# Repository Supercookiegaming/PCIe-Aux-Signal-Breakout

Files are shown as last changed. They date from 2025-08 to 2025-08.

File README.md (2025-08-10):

# PCIe Auxiliary Signal Breakout Card


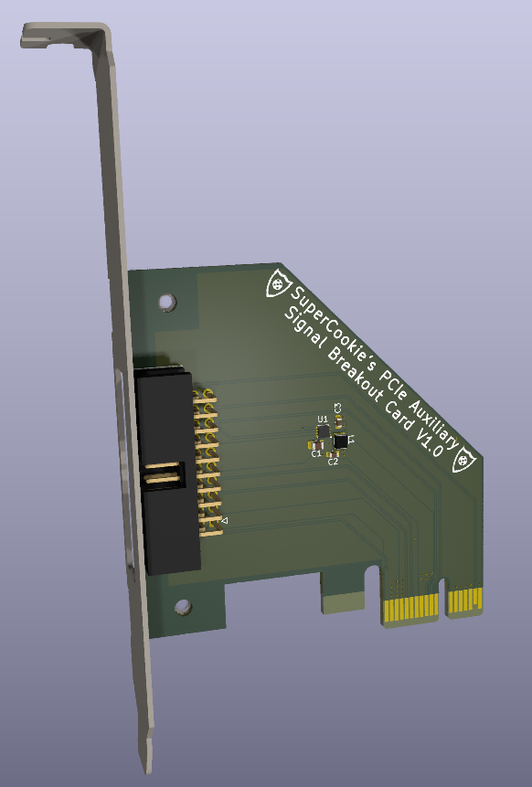
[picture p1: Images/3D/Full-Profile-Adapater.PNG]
3D Card Render


## Overview
The PCIe Auxiliary Signal Breakout Card is designed to make the auxiliary signals in a PCIe connection available to the user. This includes SMBus and JTAG. The card also provides 12V, 5V and 3.3V power and the PCIe reset signal which also functions as a 3.3V and 12V power good signal.

## Specifications

* 10W Total Power Output
    * Up to 3.0A on 3.3V
    * Up to 1.0A on 5V (optional)
    * Up to 0.5A on 12V
    * Up to 0.375A on 3.3V Aux
* Open-Drain SMBus
    * 3.3V Signal Levels
* IEEE Standard 1149.1 JTAG
    * 3.3V Signal Levels
* Always on 3.3V Aux rail
* Standard and Low Profile Brackets included

## Pinout

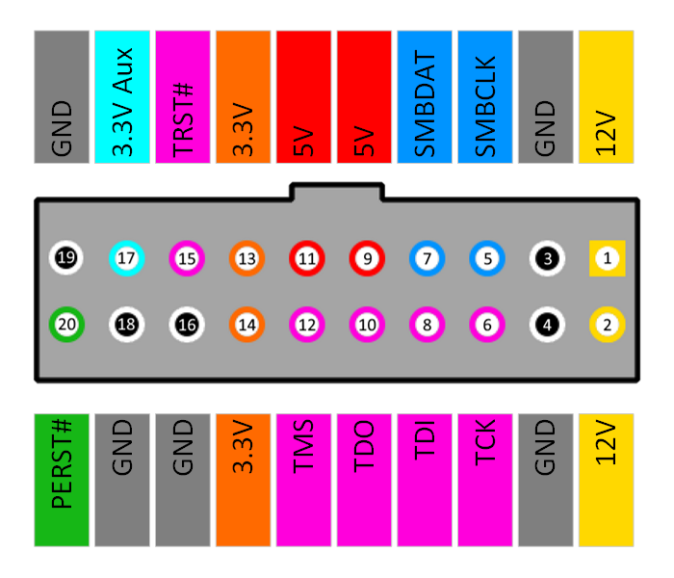
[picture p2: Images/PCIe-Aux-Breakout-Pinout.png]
Header Pinout


## Instructions

* [Ordering Instructions](Instructions/PCB_Order_Instructions.md)
* [KiCad Instructions](Instructions/KiCad_Install_Instructions.md)
* [Soldering Instructions](Instructions/Soldering_Instructions.md)
* [3D Printing Instructions](3D-Printing)
  
## Issues and Feature Requests

| Issue/Feature | Issue Number | Status | Version Milestone |
|---|---|---|---|

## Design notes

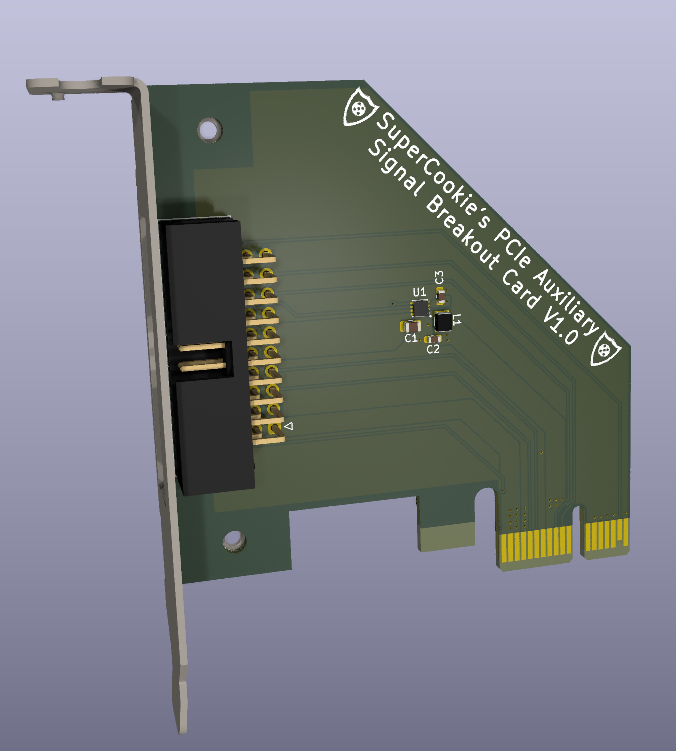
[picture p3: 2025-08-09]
Images/3D/Low-Profile-Adapater.PNG

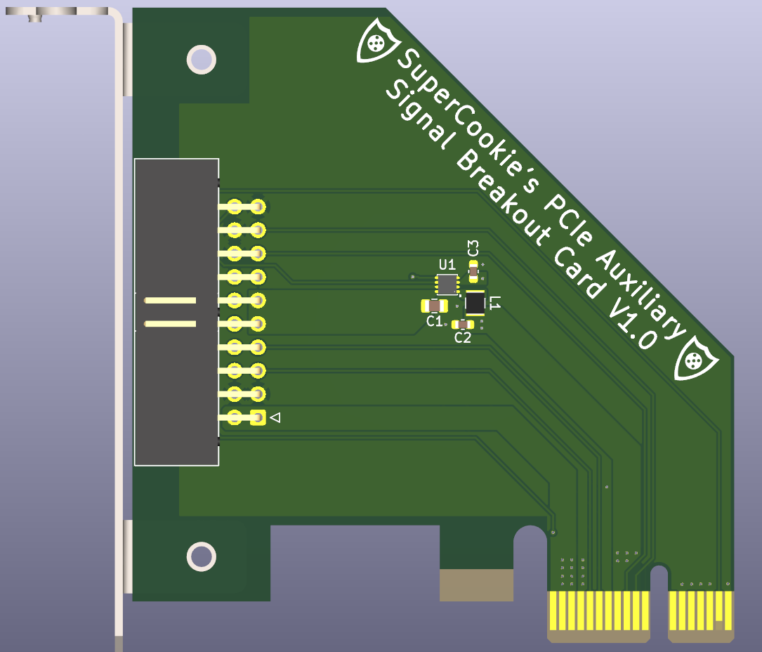
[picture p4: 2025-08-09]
Images/2D/Low-Profile-Adapter-Front.PNG

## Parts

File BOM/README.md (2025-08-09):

## Bill Of Materials
The components for this project are designed to be flexible. 

The `BHR-20-HUA` is the cheapest IDC header I found on Digikey at the time of writing this. It can be replaced with any IDC header or standard 0.1" pitch header. A right able connector is need to have the header accessible to the PCI bracket.

The `MIC2876-5.0YMT-TR` boost converter used can be swapped for any fixed output varitants of the MIC2876 or MIC2875 boost converters. If the 5V output is not need then the boost converter and supporting passives should not be installed. The 5V pins can swaped to GND by not installing the boost converter and bridging the pins of C1, for example with an 0805 0Ω resistor. 

A Bill of Materials with links to the parts on Digikey can be found in the excel sheet in this folder.

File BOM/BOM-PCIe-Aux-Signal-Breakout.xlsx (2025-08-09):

Board QTY | 1
Total Price | 1.61
Board Designator | Part Number | Part Purpose | QTY per Board | Unit Price | QTY Needed | Total Price | Link
J3 | BHR-20-HUA | Singal Breakout Header | 1 | 0.61 | 1 | 0.61 | https://www.digikey.com/en/products/detail/adam-tech/BHR-20-HUA/9832572
U1 | MIC2876-5.0YMT-TR | 5V Boost Converter | 1 | 0.62 | 1 | 0.62 | https://www.digikey.com/en/products/detail/microchip-technology/MIC2876-5-0YMT-TR/5283840
L1 | WIP252012S-1R0MLDG | 1uH Boost Converter Inductor | 1 | 0.10 | 1 | 0.1 | https://www.digikey.com/en/products/detail/inpaq-technology-co-ltd/WIP252012S-1R0MLDG/20486665
C1 | CL21A226MQQNNNE | 22uF 5V Boost Converter Output Cap | 1 | 0.12 | 1 | 0.12 | https://www.digikey.com/en/products/detail/samsung-electro-mechanics/CL21A226MQQNNNE/3886758
C2 | CL10A475KP8NNNC | 4.7uF 5V Boost Converter Input Cap | 1 | 0.08 | 1 | 0.08 | https://www.digikey.com/en/products/detail/samsung-electro-mechanics/CL10A475KP8NNNC/3886702
C3 | CL10B105KP8NNNC | 1uF 5V Boost Converter Input Cap | 1 | 0.08 | 1 | 0.08 | https://www.digikey.com/en/products/detail/samsung-electro-mechanics/CL10B105KP8NNNC/3887604

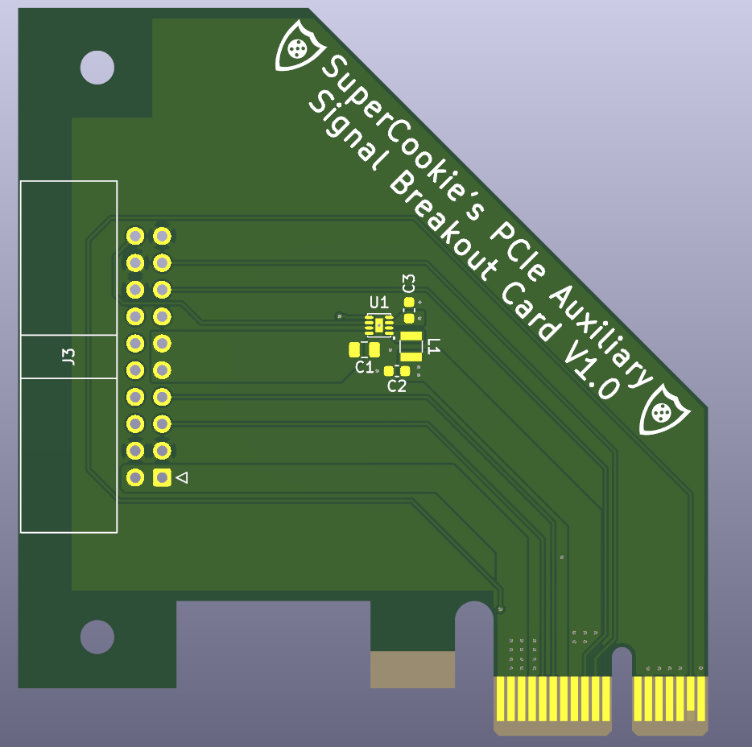
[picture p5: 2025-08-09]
Images/2D/Low-Profile-Adapter-Front-No-Components.PNG

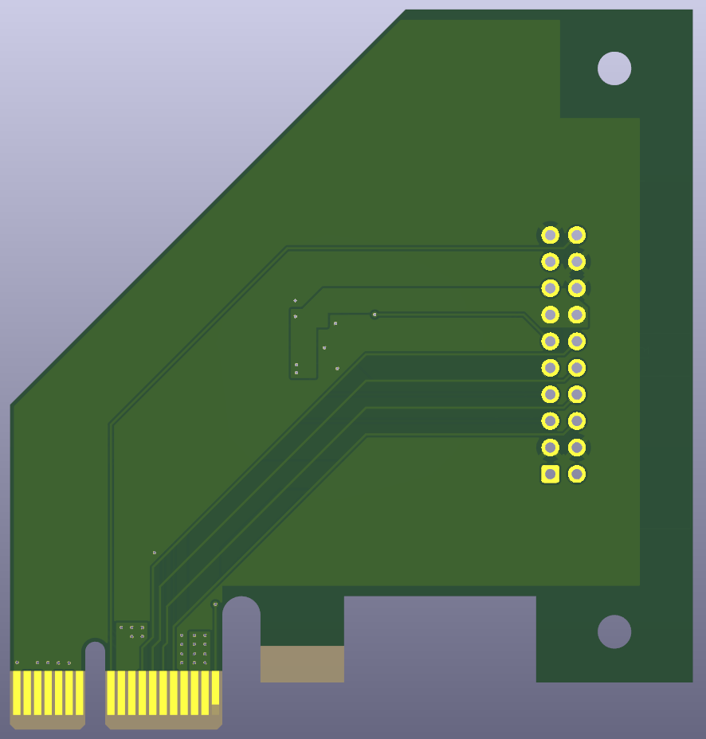
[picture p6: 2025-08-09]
Images/2D/Low-Profile-Adapter-Back-No-Components.PNG

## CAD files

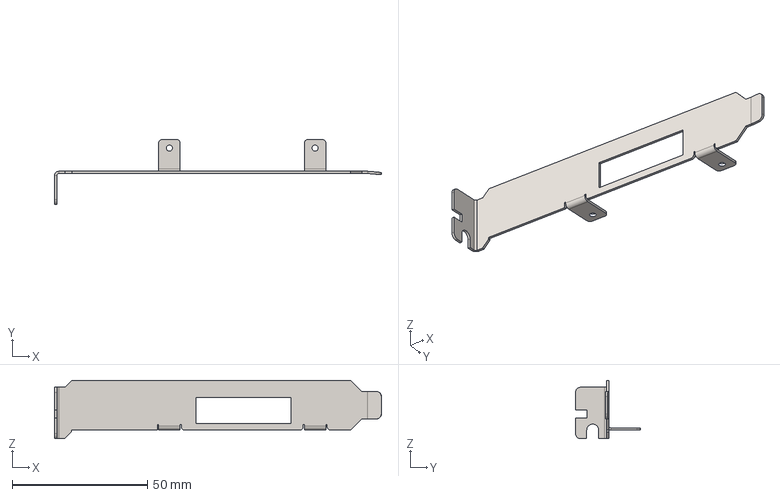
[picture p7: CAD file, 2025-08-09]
3D-Models/PCIexpress_Aux_bracket_full_adapter.step
120.9 x 24.0 x 21.6 mm

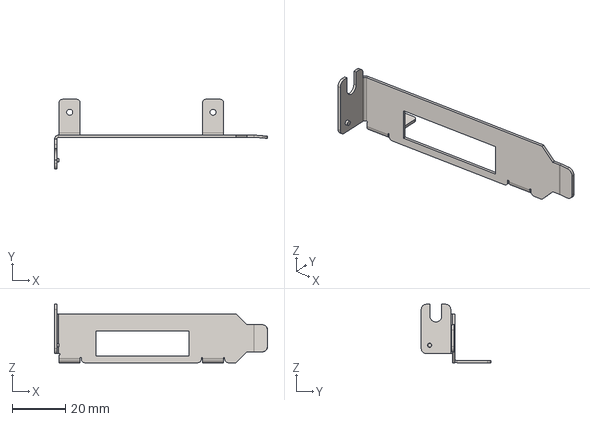
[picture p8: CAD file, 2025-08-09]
3D-Models/PCIexpress_Aux_bracket_low.step
80.1 x 26.1 x 22.0 mm

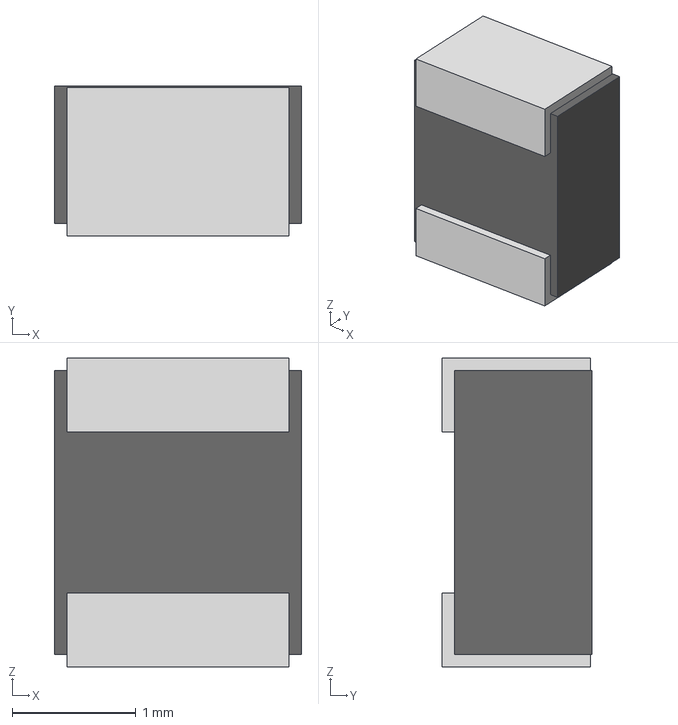
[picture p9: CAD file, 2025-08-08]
KiCad/PCIe-Aux-Signal-Breakout-Library/PCIe-Aux-Signal-Breakout-3D-Library/Inpaq 2520 Inductor.stp
2.00 x 1.21 x 2.50 mm

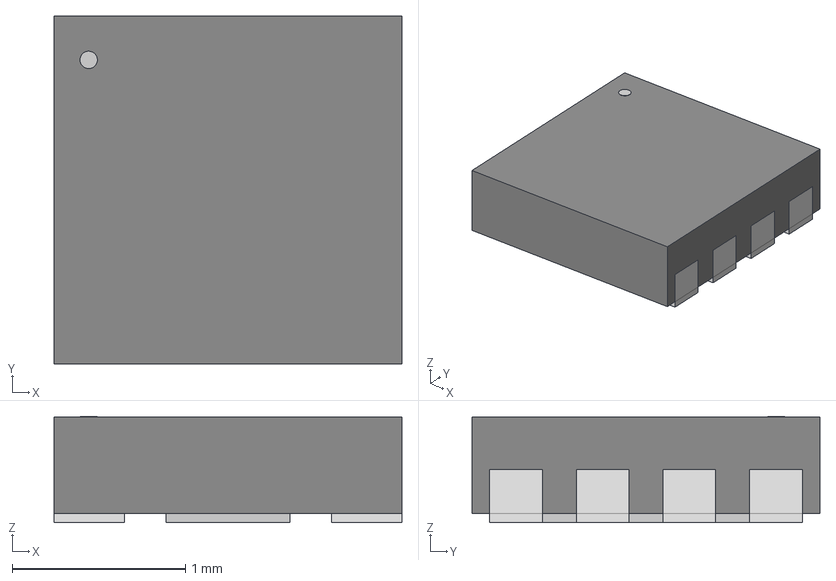
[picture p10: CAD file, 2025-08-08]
KiCad/PCIe-Aux-Signal-Breakout-Library/PCIe-Aux-Signal-Breakout-3D-Library/UDFN8_2X2_MCH.step
2.01 x 2.01 x 0.612 mm

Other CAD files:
3D-Printing/PCIexpress-Aux-bracket-full-adapter.stl
3D-Printing/PCIexpress-Aux-bracket-low.stl

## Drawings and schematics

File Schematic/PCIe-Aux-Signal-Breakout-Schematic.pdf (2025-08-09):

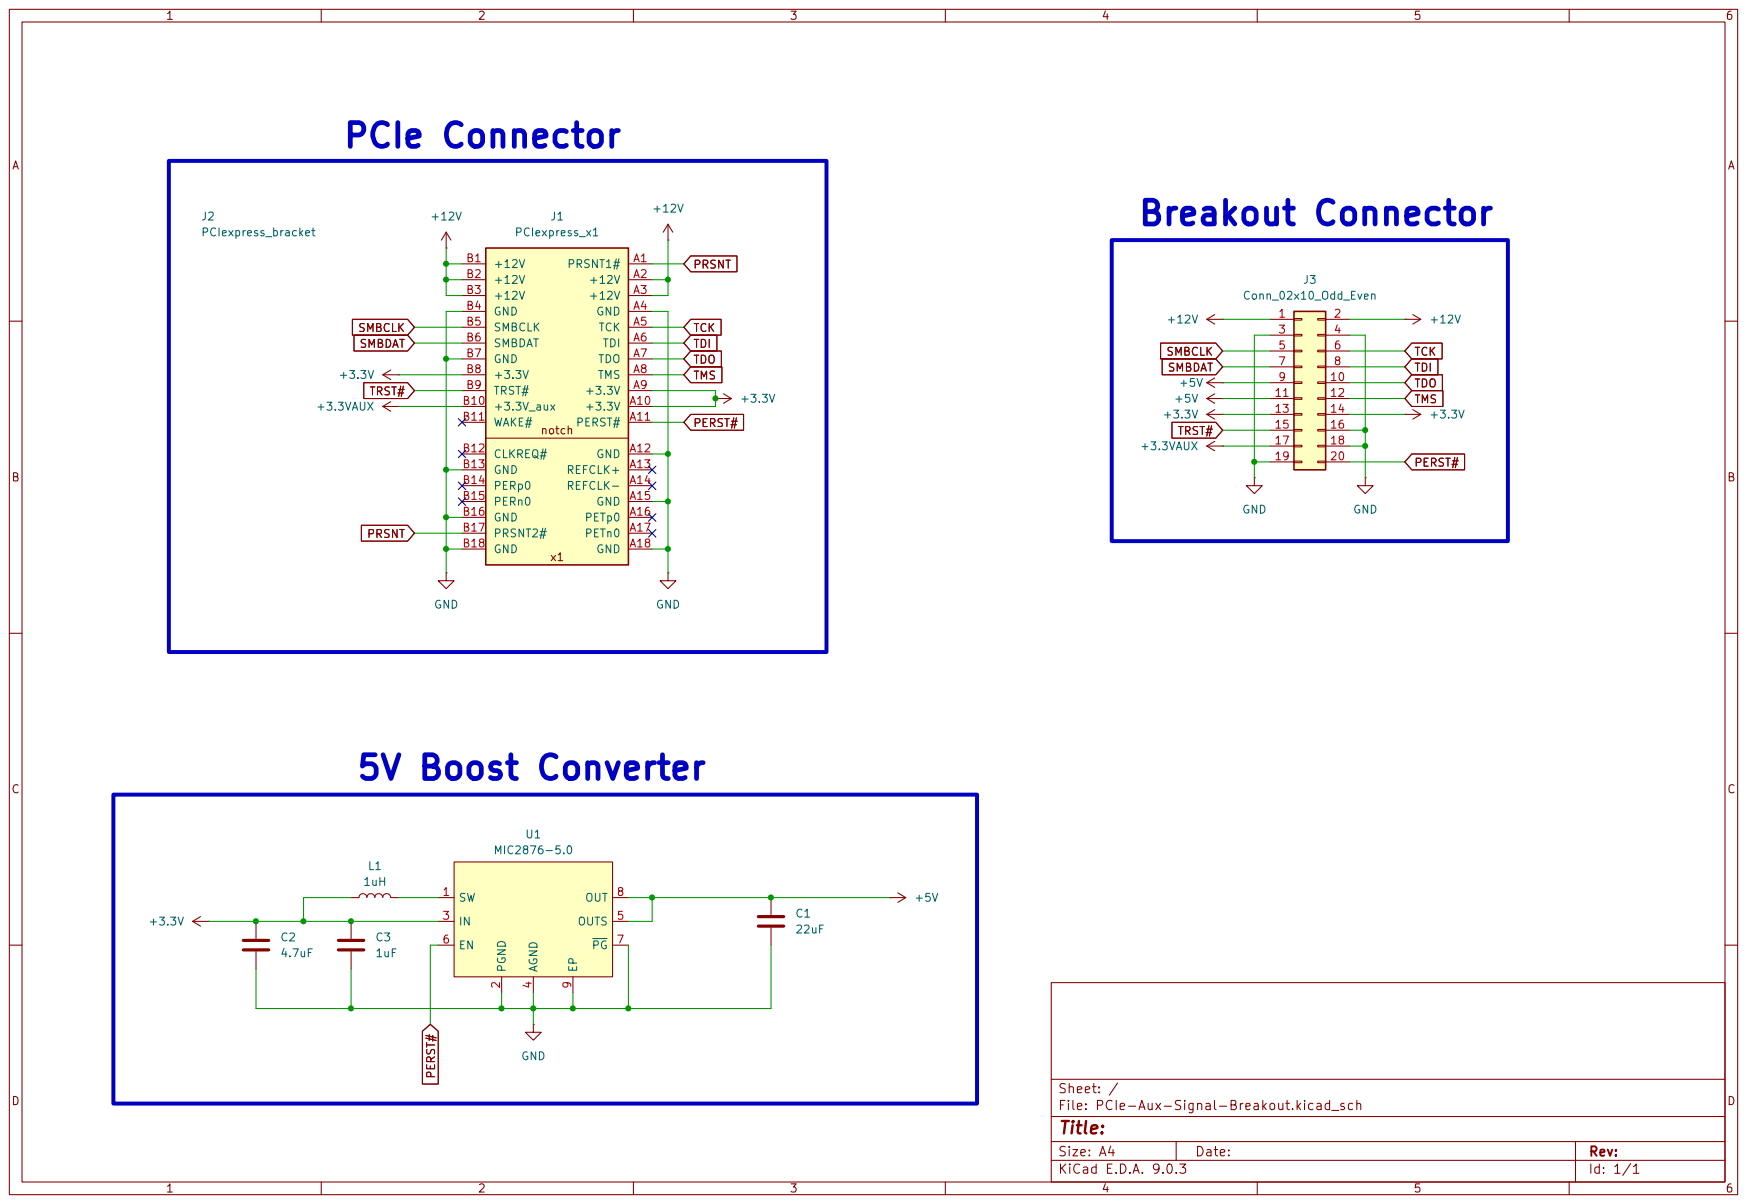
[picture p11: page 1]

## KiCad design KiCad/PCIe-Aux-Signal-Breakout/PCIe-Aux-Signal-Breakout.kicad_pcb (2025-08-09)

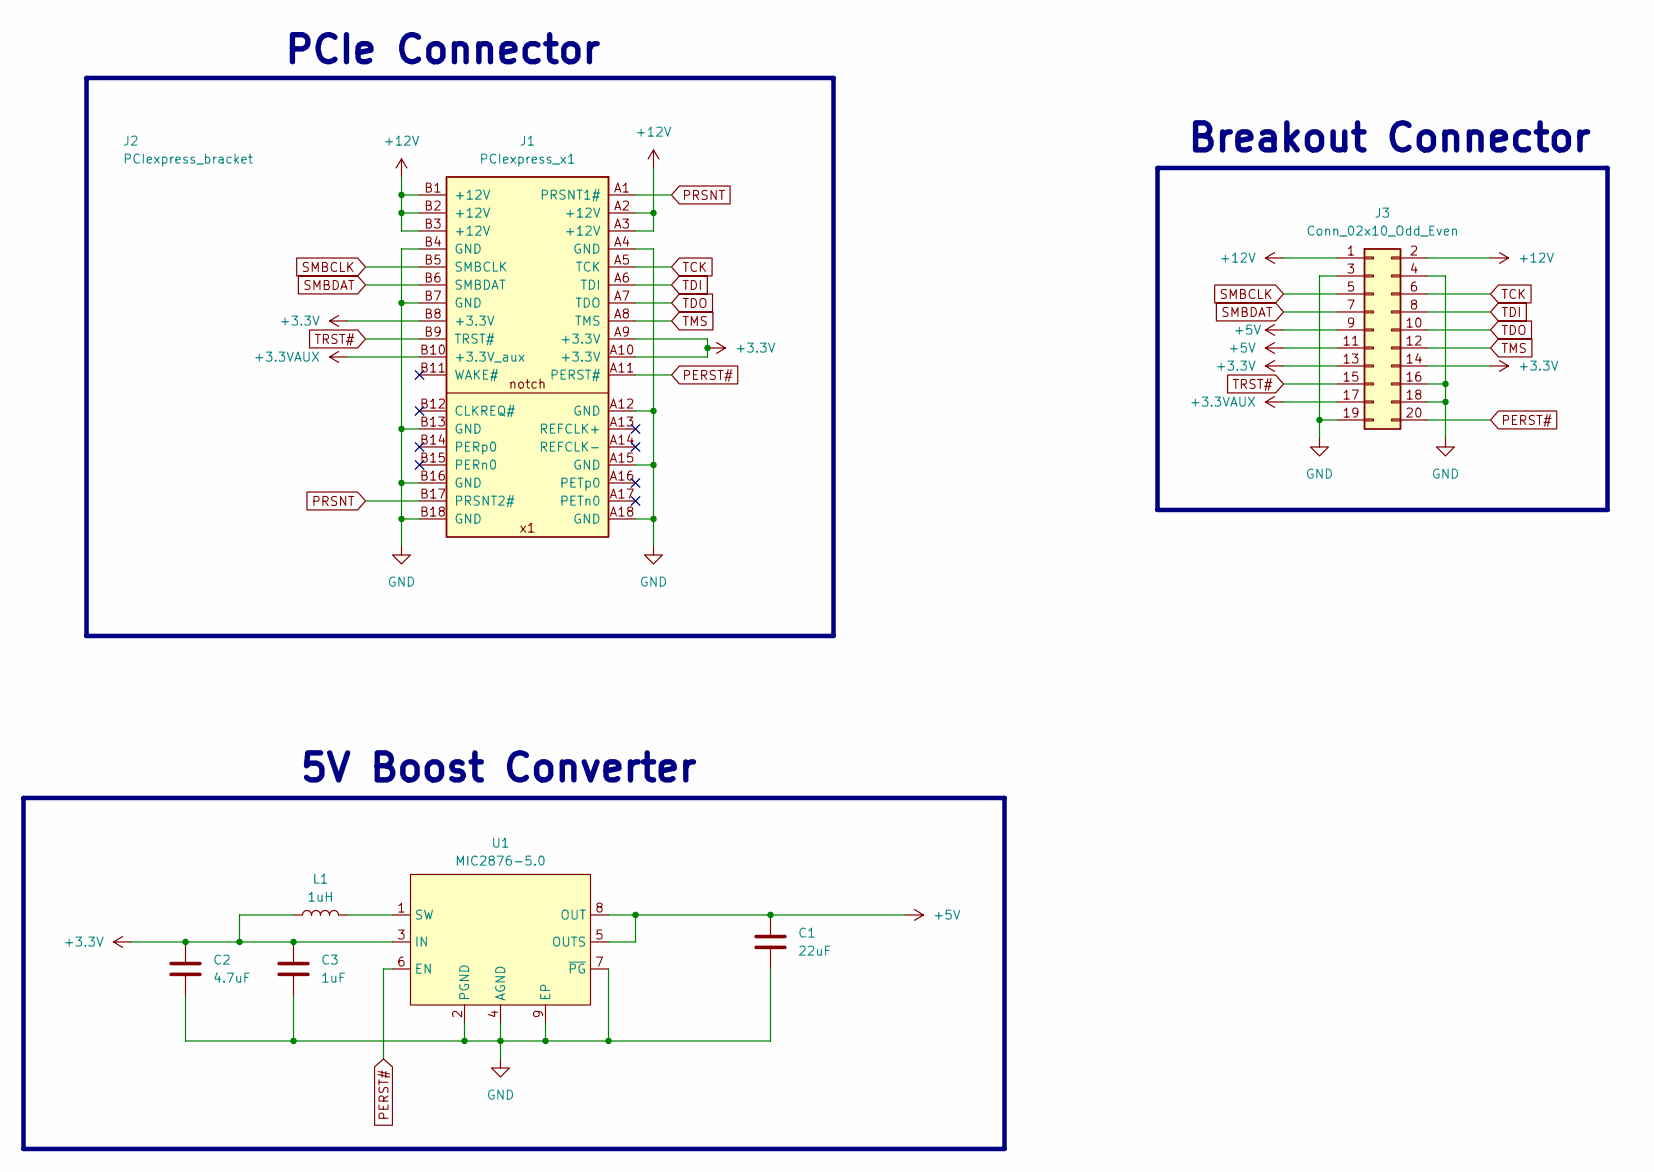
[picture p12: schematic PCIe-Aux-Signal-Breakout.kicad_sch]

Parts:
C1: 22uF; C_0805_2012Metric
C2: 4.7uF; C_0603_1608Metric
C3: 1uF; C_0603_1608Metric
J1: PCIexpress_x1
J2: PCIexpress_bracket; PCIexpress_bracket_low
J3: Conn_02x10_Odd_Even; IDC-Header_2x10_P2.54mm_Horizontal
L1: 1uH; L_2520_INPAQ
U1: MIC2876-5.0; 8-Lead UDFN

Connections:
+3.3V: C2.1, C3.1, J1.A9 (+3.3V), J1.A10 (+3.3V), J1.B8 (+3.3V), J3.13, J3.14, L1.1, U1.3 (IN)
+3.3VAUX: J1.B10 (+3.3V_aux), J3.17
+5V: C1.1, J3.9, J3.11, U1.5 (OUTS), U1.8 (OUT)
+12V: J1.A2 (+12V), J1.A3 (+12V), J1.B1 (+12V), J1.B2 (+12V), J1.B3 (+12V), J3.1, J3.2
GND: C1.2, C2.2, C3.2, J1.A4 (GND), J1.A12 (GND), J1.A15 (GND), J1.A18 (GND), J1.B4 (GND), J1.B7 (GND), J1.B13 (GND), J1.B16 (GND), J1.B18 (GND), J3.3, J3.4, J3.16, J3.18, J3.19, U1.2 (PGND), U1.4 (AGND), U1.7 (~PG), U1.9 (EP)
unnamed: L1.2, U1.1 (SW)
PERST#: J1.A11 (PERST#), J3.20, U1.6 (EN)
PRSNT: J1.A1 (PRSNT1#), J1.B17 (PRSNT2#)
SMBCLK: J1.B5 (SMBCLK), J3.5
SMBDAT: J1.B6 (SMBDAT), J3.7
TCK: J1.A5 (TCK), J3.6
TDI: J1.A6 (TDI), J3.8
TDO: J1.A7 (TDO), J3.10
TMS: J1.A8 (TMS), J3.12
TRST#: J1.B9 (TRST#), J3.15

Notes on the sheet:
5V Boost Converter
Breakout Connector
PCIe Connector

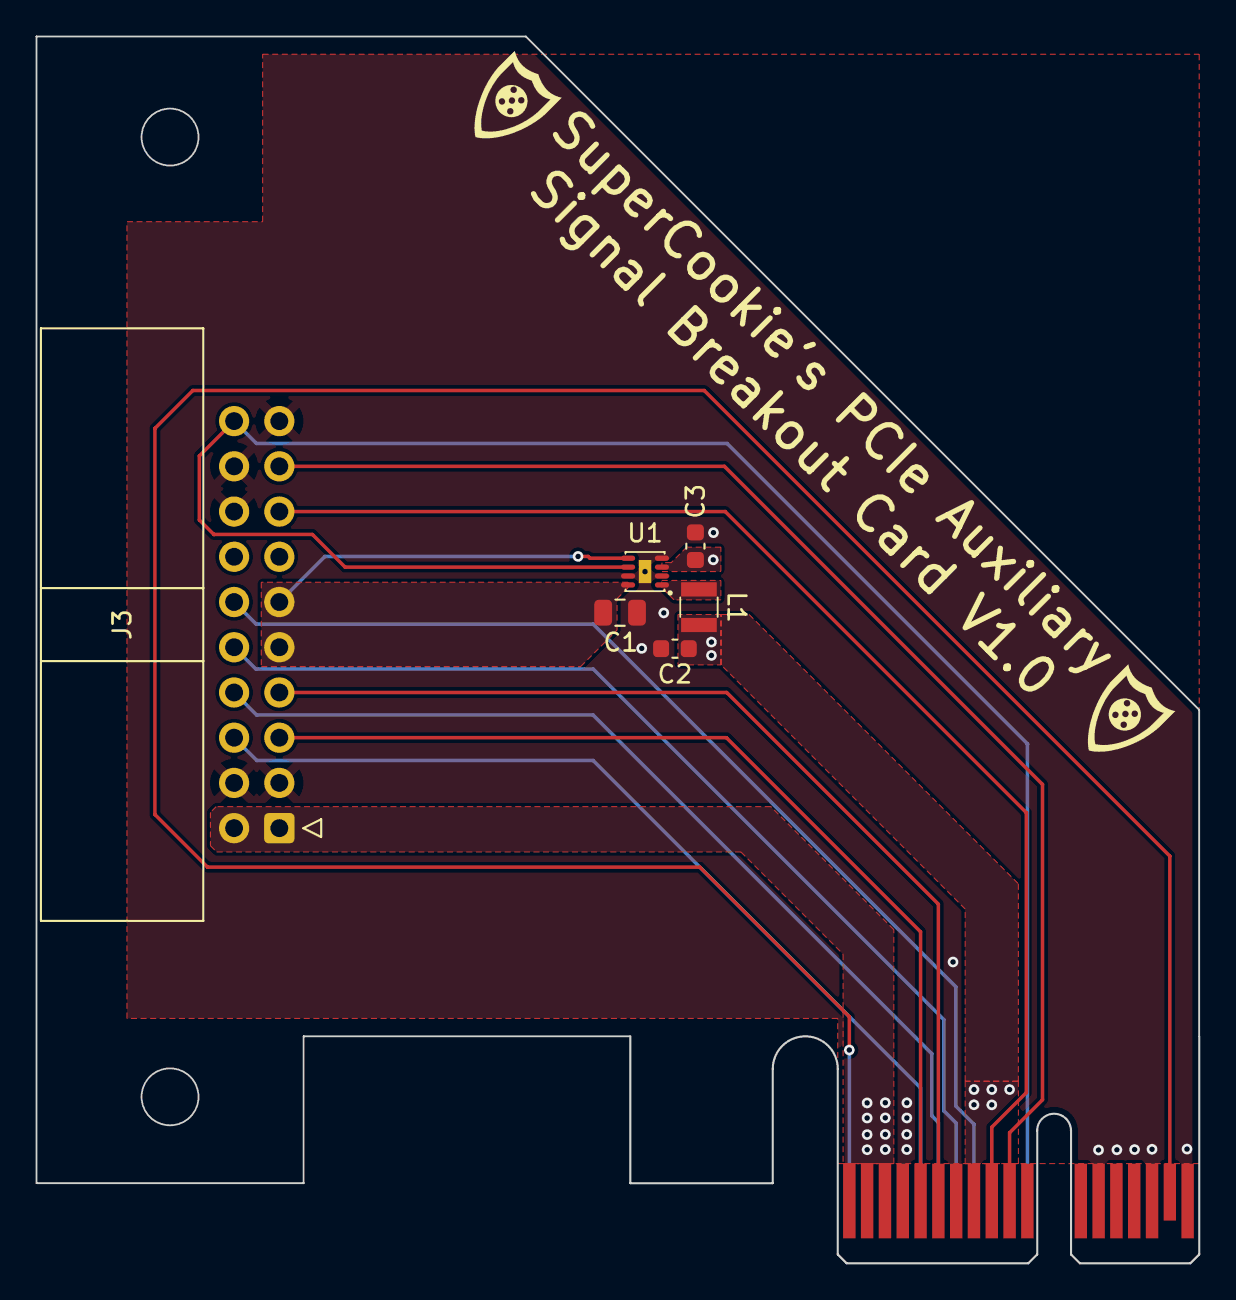
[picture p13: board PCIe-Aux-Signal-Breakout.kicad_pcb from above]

Board: 2 copper layers, 65.3 x 68.9 mm, 8 parts (0 on the bottom side), 15 nets.

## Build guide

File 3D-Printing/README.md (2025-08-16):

## 3D Printing Instructions
After printing both brackets its not advised to 3D print the brackets. The thin nature of the brackets and number of overhangs makes it hard to get a clean bracket. The low profile bracket was somewhat easier to print compared to the full profile bracket. I will be making a 3D printed Jig so that users can cut out the right area from a blank metal bracket.

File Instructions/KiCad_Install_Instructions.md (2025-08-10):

## Kicad Install Instructions

This project is dependant on my [PCIexpress-KiCad repository](https://github.com/Supercookiegaming/PCIexpress-KiCad/commit/efb5ea7d4e6b977a15ab6a312c45c6d05c768622). The linked commit of PCIexpress-KiCad is the version used in this project.

1. Clone the repository and its dependants to your desired location using your preferred method. For example 

   `cd desired-repository-location`
   
   `git clone https://github.com/Supercookiegaming/PCIe-Aux-Signal-Breakout.git`
   
2. Install the symbol librarys by opening KiCad 9 then going to Prefrences>Manage Symbol Librarys...

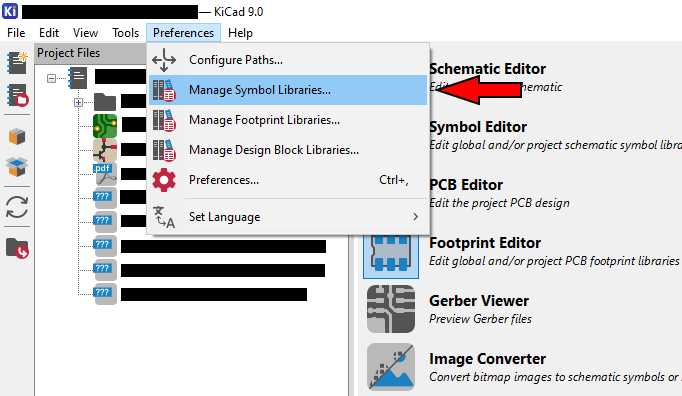
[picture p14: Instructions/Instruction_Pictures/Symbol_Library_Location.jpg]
Symbol_Manager_Location
    
   
3. Click the plus symbol in the Symbol Library window. The number of rows added must be equal to the number of libraries you are adding.

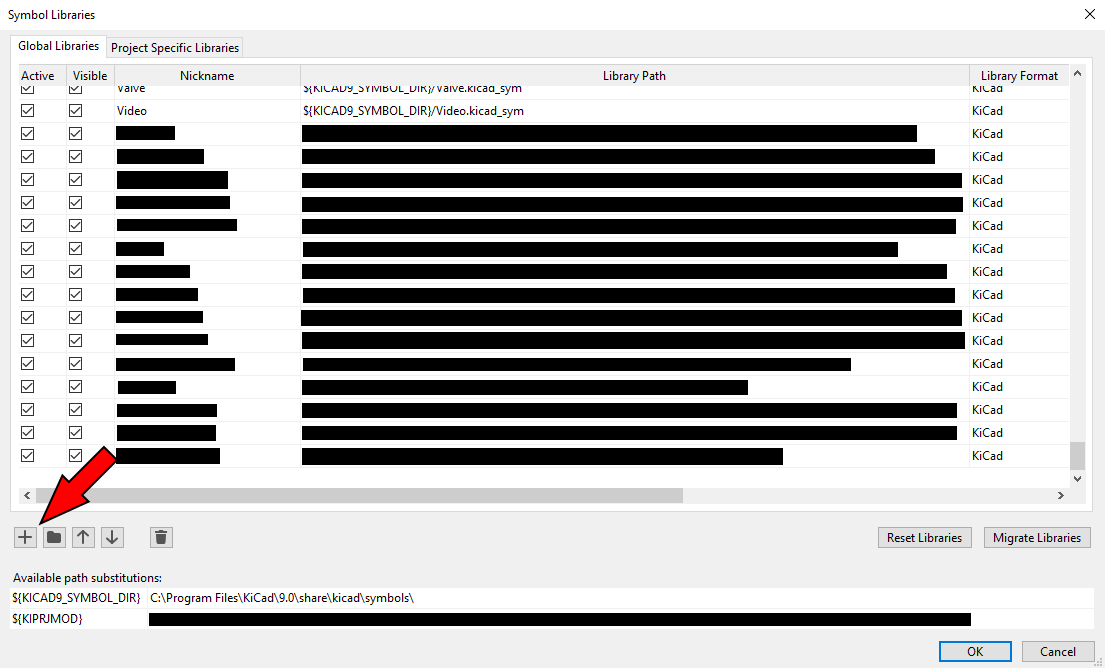
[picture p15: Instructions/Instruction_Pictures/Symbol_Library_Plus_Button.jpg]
Symbol Plus Button
    
   
4. Set the Nickname of the new row(s) to

   `PCIe-Aux-Signal-Breakout-Symbol-Library`

5. Set the Library Path to 

   `respository-location/PCIe-Aux-Signal-Breakout/KiCad Files/PCIe-Aux-Signal-Breakout-Symbol-Library.kicad_sym`

   Example of correctly added Symbol Libraries

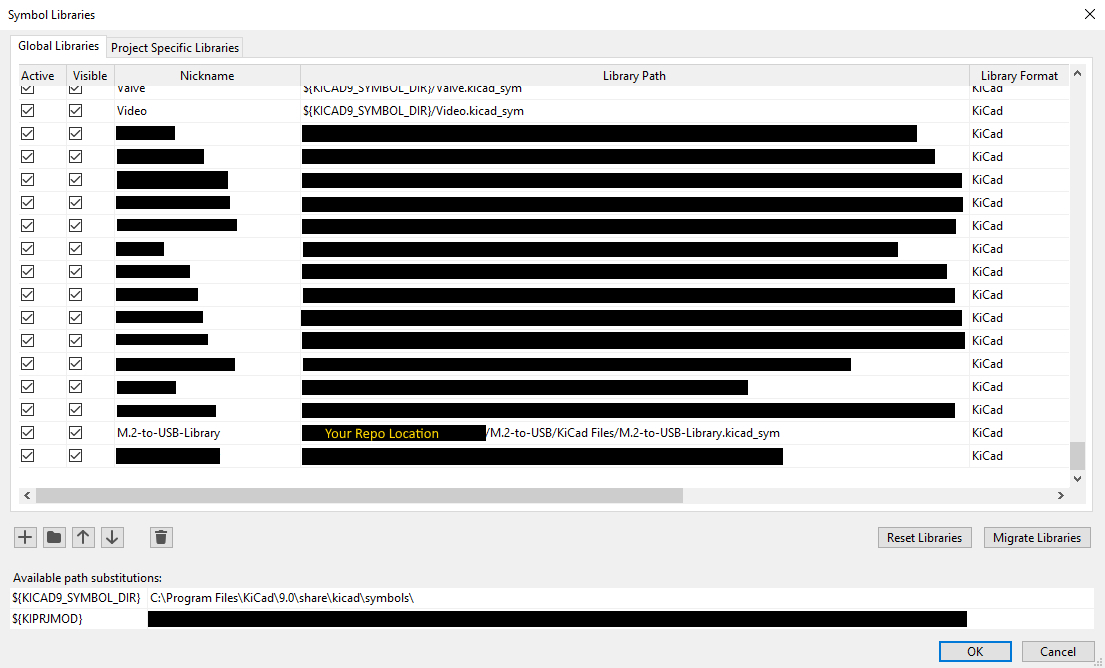
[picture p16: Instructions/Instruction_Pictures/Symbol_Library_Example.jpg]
Correctly added Symbol Libraries
   
   
6. Click Ok to save.
7. Install the footprint librarys by going to Prefrences>Manage Footprint Librarys...

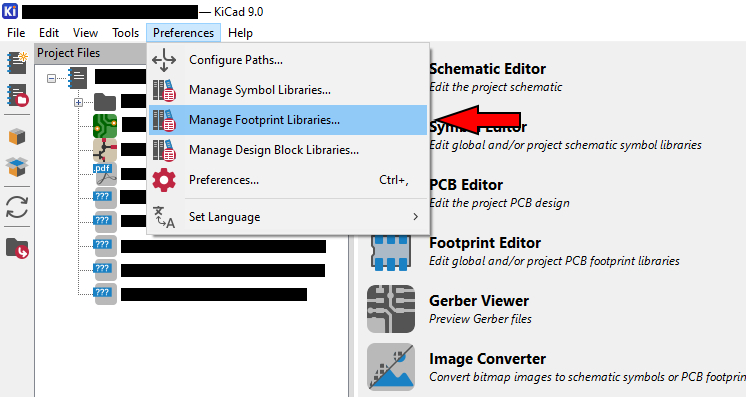
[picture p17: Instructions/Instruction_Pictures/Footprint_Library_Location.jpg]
Footprint Manager Location
    
    
8. Click the plus symbol in the Footprint Library window. The number of rows added must be equal to the number of libraries you are adding.

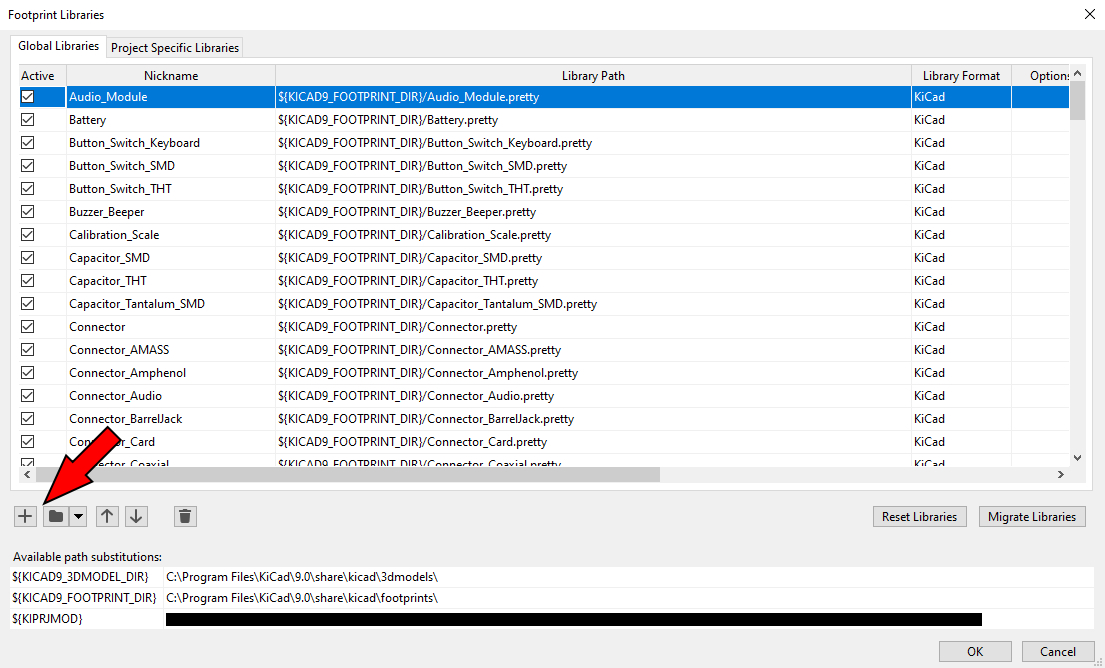
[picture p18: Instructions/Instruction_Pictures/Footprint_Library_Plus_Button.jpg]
Footprint Plus Button
    
    
9. Set the Nickname of the new row(s) to

    `PCIe-Aux-Signal-Breakout-Footprint-Library`

10. Set the Library Path to 

    `respository-location/PCIe-Aux-Signal-Breakout/KiCad Files/PCIe-Aux-Signal-Breakout-Footprint-Library.pretty`

    Example of correctly added Footprint Libraries:

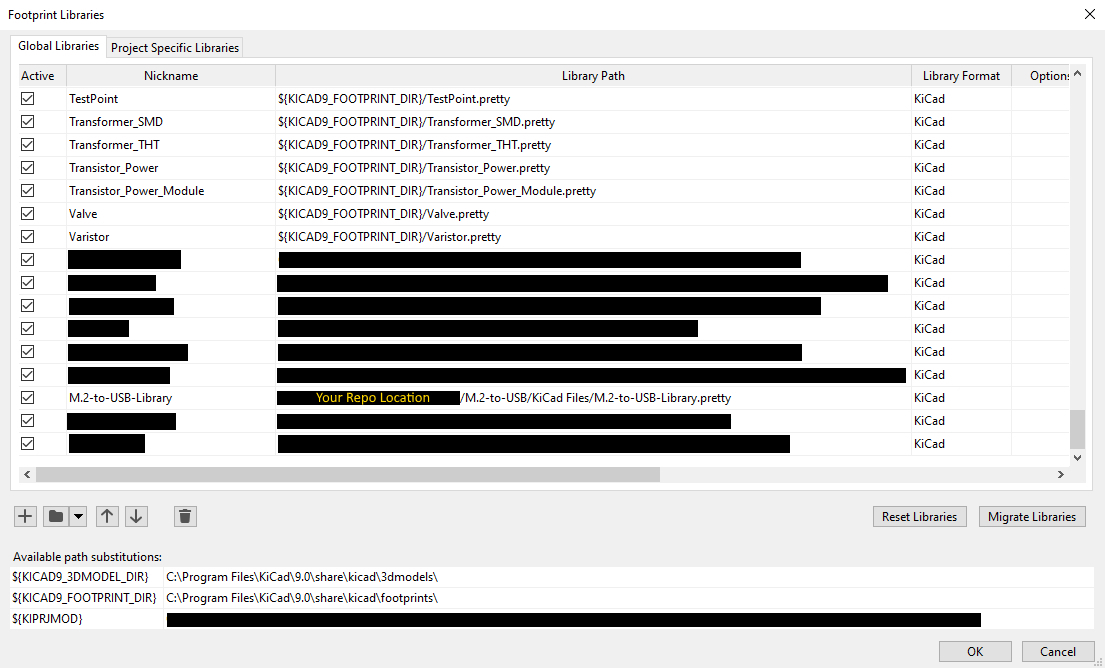
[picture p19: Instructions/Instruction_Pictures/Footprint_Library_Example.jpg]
Correctly added Footprint Libraries
    
11. Click Ok to save.   
12. Add the library's internal path by going to Prefrences > Configure Paths...

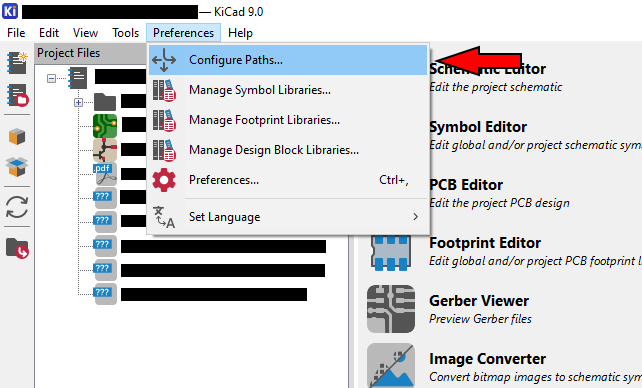
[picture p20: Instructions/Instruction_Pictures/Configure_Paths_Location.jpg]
Configure Path Loction
    
    
13. Click the plus symbol in the Configure Paths window.

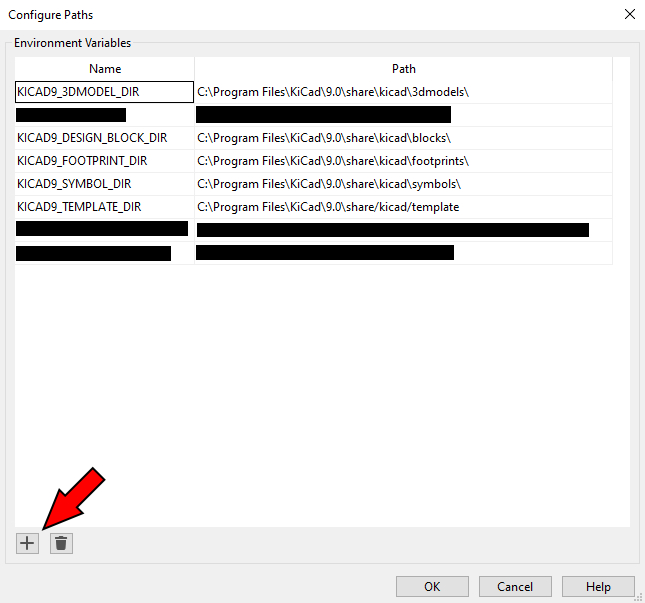
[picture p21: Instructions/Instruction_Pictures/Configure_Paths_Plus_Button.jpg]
Path Plus Button
    
    
14. Set the Name to

    `KICAD9_USER_PCIEAUXBRK_REPO_DIR`

15. Set the Path to root folder of the repository
    
     `repository-location/PCIe-Aux-Signal-Breakout`
    
    Example of correctly added path:

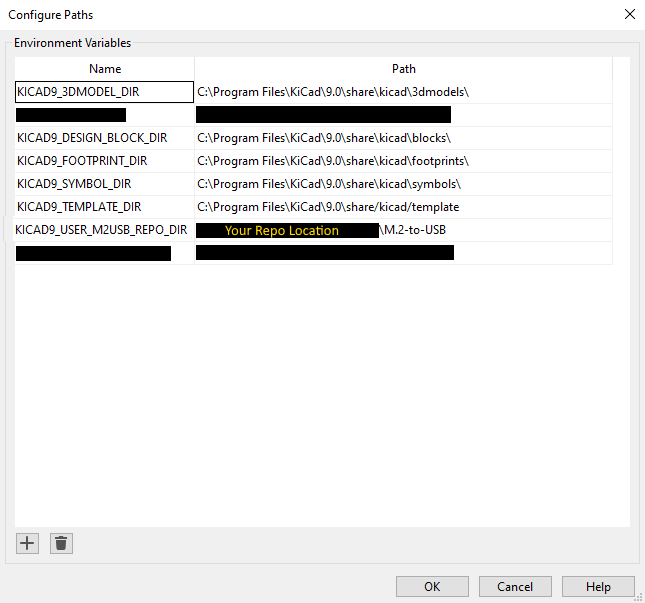
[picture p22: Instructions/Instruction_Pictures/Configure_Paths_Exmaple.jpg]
correctly added path
    

16. Click Ok to Save

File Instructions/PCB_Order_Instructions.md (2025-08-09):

## PCB Ordering Instructions

This project is designed to be built using most PCB manufacturing services like JLCPCB, PCBWay or OshPark etc. 

It recommened to also purchase a solder paste stencil for this board. 

### Required Options for this Design
1. Upload the Gerber Zip file found in [PCIe-Aux-Signal-Breakout/Gerber](Gerber) to your manufacturer of choice.

2. Set the Layers to `2`, if not already done so by the tool.

3. Select a PCB thickness of `1.6mm`.

4. Select `Yes` for Gold Fingers.

### Recommended Options
1. It is recommended to get the PCIe card edge plated with Hard Gold. If Hard Gold is not available ENIG plating will work but will reduce the number of insertions. 

### Stencil Ordering Instructions
1. The Stencil Side should be set to `Top only`.

2. It is recommended that a smaller custom size is selected, for example `50 x 50 mm`.

3. Paste the following into the Stencil Remark text box `Please follow the solder paste layer only, and ignore the difference between the solder mask layer and solder paste layer.`

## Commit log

2025-08-08 Created KiCad Files
    created kicad project
    added project kicad library
    added gitignore file
    [Inpaq 2520 Inductor.stp, PCIe-Aux-Signal-Breakout.kicad_pcb, PCIe-Aux-Signal-Breakout.kicad_sch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]
2025-08-09 started pcb design
    [PCIe-Aux-Signal-Breakout.kicad_pcb, PCIe-Aux-Signal-Breakout.kicad_sch]
2025-08-09 finished v1.0 design
    finished v1.0 pcb
    added low and standard profile pcie bracket with custom connector cutout
    made gerber files
    added instruction files
    added images of the board
    added BOM
    [BOM-PCIe-Aux-Signal-Breakout.xlsx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]
2025-08-09 added drill files to gerber
    [PCIe-Aux-Signal-Breakout-NPTH.drl, PCIe-Aux-Signal-Breakout-PTH.drl]
2025-08-09 Added Schematic and 3D printing files
    -updated board silkscreen
    -added STL files for pcie brackets
    -added 3d model folder for assembled boards
    [PCIe-Aux-Signal-Breakout-B_Cu.gbr, PCIe-Aux-Signal-Breakout-B_Mask.gbr, PCIe-Aux-Signal-Breakout-B_Paste.gbr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]
